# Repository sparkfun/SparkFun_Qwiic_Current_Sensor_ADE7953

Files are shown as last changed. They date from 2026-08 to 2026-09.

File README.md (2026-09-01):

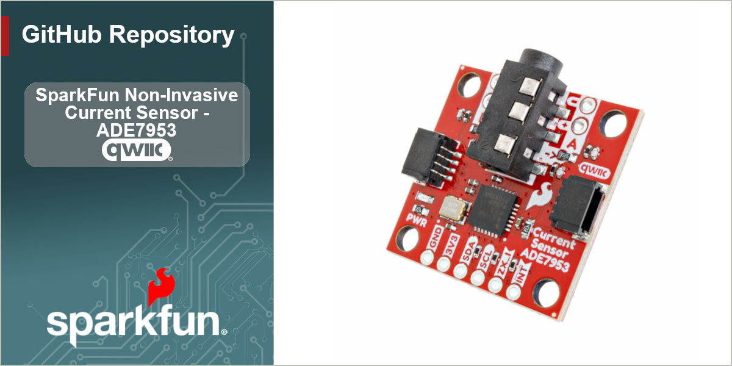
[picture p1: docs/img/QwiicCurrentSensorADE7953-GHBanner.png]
SparkFun Non-Invasive Current Sensor - ADE7953 (Qwiic) (https://www.sparkfun.com/sparkfun-non-invasive-current-sensor-ade7953-qwiic.html)


The [SparkFun Non-Invasive Current Sensor - ADE7953 (Qwiic)](https://www.sparkfun.com/sparkfun-non-invasive-current-sensor-ade7953-qwiic.html) is a dual-channel, non-invasive current measurement breakout built around the ADE7953 energy metering IC from Analog Devices. Using inexpensive SCT-013 split-core current transformers (CT clamps), you can measure AC current on up to two channels without ever breaking a wire. The board accepts CT input through a standard 3.5mm TRRS audio jack or through the A+/A- and B+/B- terminal connections, giving you flexibility for both quick prototyping and permanent installations.

Designed for our [Qwiic ecosystem](https://www.sparkfun.com/qwiic), the ADE7953 handles all of the signal conditioning, sampling, and power calculations on-chip, delivering calibrated current readings over I2C so your host microcontroller can stay focused on application logic. Whether you are building a home energy monitor, an industrial equipment dashboard, or a smart breaker panel, this board gives you metering-grade measurements in a compact, breadboard-friendly package.

## Repository Contents

* **/docs** - Documentation files for GitHub pages
* **/Documents** - Datasheets, additional product information
* **/Hardware** - KiCad design files (.kicad_sch, .kicad_pcb)
* **/Production** - Production panel files

## Documentation

* **[Library](https://github.com/sparkfun/SparkFun_ADE7953_Arduino_Library)** - Arduino library for the SparkFun Non-Invasive Current Sensor - ADE7953 (Qwiic).
* **[Hookup Guide](https://docs.sparkfun.com/SparkFun_Qwiic_Current_Sensor_ADE7953/)** - Basic hookup guide for the SparkFun Non-Invasive Current Sensor - ADE7953 (Qwiic).

## Product Versions

* **[SEN-31409](https://www.sparkfun.com/sparkfun-non-invasive-current-sensor-ade7953-qwiic.html)** - Initial release of the SparkFun Qwiic Current Sensor - ADE7953.

## License Information

This product is _**open source**_!

Please review the LICENSE.md file for license information.

If you have any questions or concerns about licensing, please contact technical support on our [SparkFun forums](https://forum.sparkfun.com/viewforum.php?f=152).

Distributed as-is; no warranty is given.

_- Your friends at SparkFun._

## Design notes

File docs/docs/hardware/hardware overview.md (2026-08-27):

# Hardware Overview

## ADE7953 Single Phase Metering IC

The ADE7953 is a single phase energy measurement IC. It measures both voltage and current along with active and reactive energy. It can also measure instantaneous rms (IRMS) voltage and current. It operates using three high-accuracy sigma-delta ADCs with two current channels. Both channels have a Programmable Gain Amplifier which can also be fine tuned with a digital gain. The ADE7953 communicates over I<sup>2</sup>C, UART and SPI (the SPI pins are *not* broken out on this Qwiic breakout).

The ADE7953 also has dedicated pins for zero-crossing for voltage (not available on this Qwiic breakout) and current to measure line frequency, cycles or to synchronize measurements with the line frequency. It supports EN 50470-1, EN 50470-3, IEC 62053-21, IEC 62053-21, IEC 62053-22 and IEC 62053-23 standards. It accepts a supply voltage up to 3.7V so it works perfectly at the 3.3V of the Qwiic ecosystem. For complete information on the ADE7953, refer to the [datasheet](/ref/ADE7953.pdf).

## Connectors

### Qwiic

The board has a pair of Qwiic connectors for easy integration into a Qwiic circuit. These 4-pin connectors are tied to the board's 3.3V, Ground, SDA and SCL pins to power and communicate over a Qwiic connection by default.

### Current Sensing Connections

The board routes the ADE7953's Channel A current input to a 3.5mm TRRS jack for use with a compatible current transformer/current clamp. The board design is intended to work with a current transformer with a ratio of 2000:1. Channel A and Channel B are also routed to plated through-holes on either side of the TRRS jack for those who prefer a soldered connection or want to use Channel B. Note, the through-hole connections to the ADE7953's current channels operate at a 1:1 ratio and cannot safely measure currents above 100mA without adding in a current transformer with a compatible CT ratio. 

### Plated Through-Hole Header

The 0.1"-spaced plated through-hole (PTH) header on the bottom of the board breaks out the power pins (3.3V and Ground), communication (SDA/TX and SCL/RX) pins, Interrupt and Zero Cross signal pins. 

The Interrupt pin is an active LOW digital output. It can be configured to fire on a variety of events such as overcurrent, zero-crossing or cycle completion without polling. It can be configured to trigger on single events or multiple events at the same time.

The Zero Cross signal (labeled ZX_I) outputs a pulse each time the current waveform crosses zero. This pulse is great for determining line frequency and syncrhonizing measurements to the AC cycle of a connected load.

## LED

This board has a single LED labeled **PWR**. This red LED is a simple status LED to indicate when the board has power.

## Solder Jumpers

The Non-Invasive Current Sensor - ADE7953 has four solder jumpers labeled **SCLK** (some boards may have this jumper mislabeled as SLCK), **CS**, **I<sup>2</sup>C** and **LED**. The list below outlines their functionality, default state and any notes on their use.

* **SCLK** - This three-way jumper works with the CS jumper to set the communication interface used by the ADE7953. The jumper pulls the SCLK pin HIGH/3.3V by default to use the I<sup>2</sup>C interface. Sever the trace between the "top" and center pad and connect the center pad to the "bottom" to pull SCLK LOW/GND to enable UART. Leave the center pad disconnected from the other two pins to enable SPI communication. **NOTE**: This board does *not* route the ADE7953's SCLK and CS pins to dedicated PTHs so SPI is not *technically* supported on this board. Refer to the Troubleshooting section for more information on SPI.
* **CS** - This jumper works with the SCLK jumper to set the ADE7953's communication interface. The jumper pulls the CS pin HIGH to enable I<sup>2</sup>C and UART. Open this jumper to disable both interfaces and to enable SPI. **NOTE**: This board does *not* route the ADE7953's SCLK and CS pins to dedicated PTHs so SPI is not *technically* supported on this board. Refer to the Troubleshooting section for more information on SPI.
* **I<sup>2</sup>C** - This three-way jumper pulls the ADE7953's SDA and SCL lines to 3.3V through a pair of **2.2k&ohm;** resistors. It is CLOSED by default. Completely open this jumper to disable the pull-ups on the data and clock pins.
* **LED** - The LED jumper completes the power LED circuit. It is CLOSED by default. Open this jumper to disable the power LED.

## Board Dimensions

This Qwiic breakout matches the standard Qwiic form-factor and measures 1" x 1" (22.5mm x 22.5mm) and has four mounting holes that fit a 4-40 screw.

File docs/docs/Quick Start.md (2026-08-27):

# Quick Start Guide

In this Quick Start Guide we'll go over how to connect the Non-Invasive Current Sensor - ADE7953 (Qwiic) to an Arduino development board along with a split-core current transformer using the board's 3.5mm TRRS jack to measure current from an AC load. This guide assumes users understand how to use the Arduino IDE and install libraries, assemble Qwiic circuits and measure AC loads with a current transformer. If you're not familiar with these topics, we recommend reading through the more detailed pages in the Hookup Guide.

## Current Sensing Assembly

* Connect the Non-Invasive Current Sensor to the RedBoard using a Qwiic cable.
* Plug the Split-Core Current Transformer into the 3.5mm TRRS jack on the Non-Invasive Current Sensor but leave the clamp **open** and disconnected from an AC load.
* Connect the board to a computer over USB.
* Have the wire for your AC load ready to insert into the Current Transformer's clamp once calibration in the Arduino example finishes.

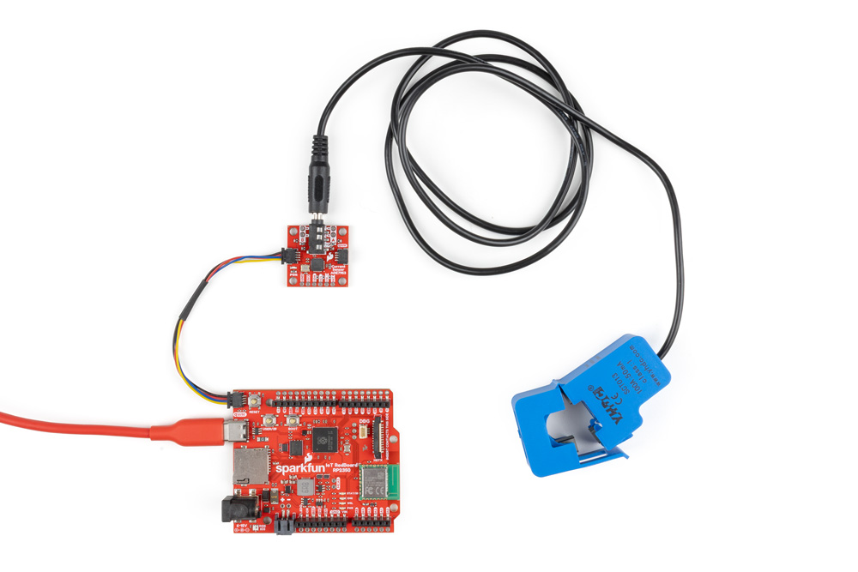
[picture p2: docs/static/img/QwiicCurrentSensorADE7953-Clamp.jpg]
Photo of completed Non-Invasive Current Sensor assembly with RedBoard IoT and Split Core Current Transformer
[]

## Arduino Example

Now we'll use the first example in the SparkFun ADE7953 Arduino library to configure and calibrate the sensor and then print out measured current in Amps. 

* Open the [Arduino IDE](https://www.arduino.cc/en/software/).
* Using the [Arduino Library Manager](https://docs.arduino.cc/software/ide-v2/tutorials/ide-v2-installing-a-library/), install the SparkFun ADE7953 Arduino Library by searching for "SparkFun ADE7953".
    * **Note**: This library was built with the [SparkFun Toolkit Library](https://github.com/sparkfun/SparkFun_Toolkit). Make sure to have the SparkFun Toolkit installed as well.
* Open "Example01_BasicCurrentReading". Select your Board and Port and click the Upload button.
* After the code finishes uploading, open the [serial monitor](https://docs.arduino.cc/software/ide-v2/tutorials/ide-v2-serial-monitor/) with the baud set to **115200**. You should see the code initialize the sensor on the bus and begin auto calibration to zero out the noise floor. Make sure the clamp is **open** during calibration. Once the code finishes calibration and prints out "Calibration done. Reading current...", close the clamp around your AC load and you'll see current measurements in Amps print out every 250ms.

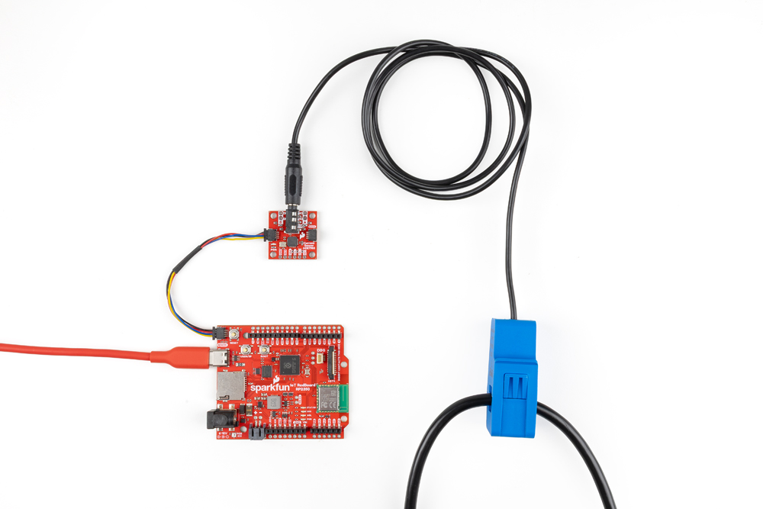
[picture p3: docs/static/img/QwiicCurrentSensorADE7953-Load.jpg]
Completed circuit measuring AC current
[]

As the name suggests, this is the most basic example in the ADE7953 library. The other examples cover how to use other features like zero-crossing, interrupt handling and detailed calibration to offset any noise floor. Read on to the Arduino Examples section for detailed information on most examples included in the library.

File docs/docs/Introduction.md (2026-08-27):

---
slug: /
---

# Introduction

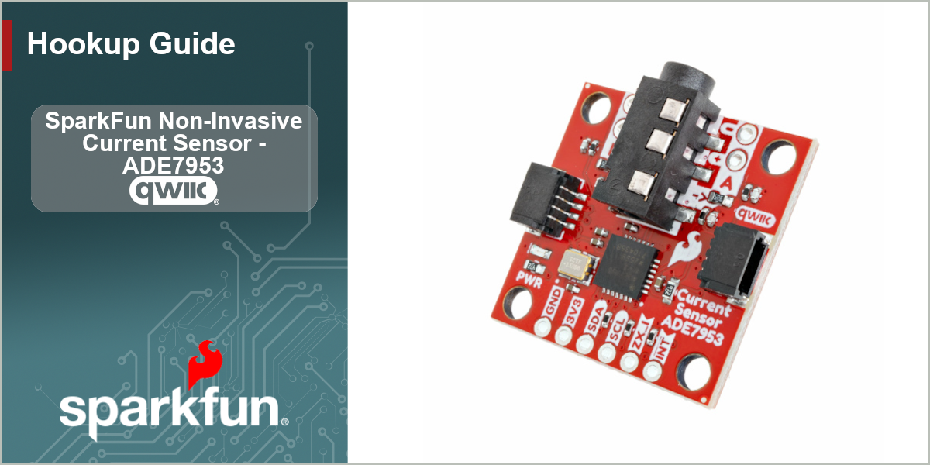
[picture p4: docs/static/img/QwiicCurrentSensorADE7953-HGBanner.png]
Non-Invasive Current Sensor Banner Image
[]

Designed to work with a non-invasive current clamp, the [SparkFun Non-Invasive Current Sensor - ADE7953 (Qwiic)](https://www.sparkfun.com/sparkfun-non-invasive-current-sensor-ade7953-qwiic.html) makes it easy to monitor the power drawn by AC devices over I<sup>2</sup>C without having to disconnect the circuit, cut or splice any wires. The ADE7953 single phase multifunction metering IC from Analog Devices is a single phase metering IC that also can measure neutral current on a second channel.

This board comes with a 3.5mm TRRS jack input that connects to the ADE7953's Current Channel A allowing users to easily connect a [non-invasive current clamp](https://www.sparkfun.com/products/31899) (sometimes referred to as a current clamp) to the board. The board also breaks out both the A and B current channels to plated-through hole pins but does <i>not</i> break out the ADE7953's voltage measurement channel so this board can only measure AC current. **Note**: The A and B PTHs have a 1:1 current transformer ratio and can only measure AC current under 100mA safely. 

In order to follow along with this guide you'll need the SparkFun Non-Invasive Current Sensor - ADE7953 (Qwiic) along with the following items:

* [Split-Core Current Transformer - 100A to 50mA](https://www.sparkfun.com/split-core-current-transformer-100a-to-50ma.html)* (or other current transformer/current clamp)
* [SparkFun RedBoard IoT - RP2350](https://www.sparkfun.com/catalog/product/view/id/17811/s/sparkfun-iot-redboard-rp2350/) (or other Arduino development board)
* [USB-C Cable](https://www.sparkfun.com/usb-a-to-usb-c-cable-1m-usb-2-0-flexible-silicone.html)
* [Qwiic Cable](https://www.sparkfun.com/flexible-qwiic-cable-100mm.html)

*Note:* The [SparkFun Non-Invasive Current Sensor Kit](https://www.sparkfun.com/sparkfun-non-invasive-current-sensor-kit.html) includes the Split-Core Current Transformer.

## Topics Covered

This document contains three main sections: **Quick Start Guide**, **Hardware** and **Software**.

The Quickstart Guide assumes a working knowledge of how to assemble and use Qwiic breakouts, measuring current with a split-core current transformer and using the Arduino IDE. It demonstrates how to connect the Non-Invasive Current Sensor - ADE7953 (Qwiic) to a split-core current transformer and then jumps right into getting the necessary software packages installed to start uploading code in just a few short minutes.

The Hardware pages include a hardware overview that provides a detailed overview of the Non-Invasive Current Sensor - ADE7953 (Qwiic). The Hardware Assembly page goes over the steps required to assemble and use the board to measure current with a compatible Arduino development board.

The Software pages give instructions on how to install the SparkFun ADE7953 Arduino Library and use some of the examples included in it.

## Resources and Documentation

The **Resources** page has the board design files (KiCad files & schematic), relevant documentation (datasheets, white papers, etc.) and other helpful links. Lastly, the **Support** pages include a Troubleshooting page that includes any helpful tips specific to this board as well as information on how to receive technical support from SparkFun.

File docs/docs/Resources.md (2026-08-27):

For more information about the Non-Invasive Current Sensor - ADE7953 (Qwiic), check out the following resources:

* [Schematic](/ref/SparkFun_Qwiic_Current_Sensor_ADE7953.pdf)
* [KiCad Files](/ref/SparkFun_Qwiic_Current_Sensor_ADE7953.zip)
* [Board Dimensions](/ref/SparkFun_Qwiic_Current_Sensor_ADE7953.png)
* [Datasheet](/ref/ADE7953.pdf) (ADE7953)
* [Arduino Library](https://github.com/sparkfun/SparkFun_ADE7953_Arduino_Library)

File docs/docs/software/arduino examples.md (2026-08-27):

# Arduino Examples

Now that we've installed the ADE7953 Library lets take a look at a few of the examples included in it.

## Example 01 - Basic Current Reading

The first example demonstrates the simplest way to read current from the ADE7953. Open the example by navigating to **File** > **Libraries** > **SparkFun ADE7953 Arduino Library** > **Example01_BasicCurrentReading**.

The example sets up the ADE7953 to operate with 16x gain and enables the high-pass filter. After initializing the sensor on the I<sup>2</sup>C bus with these settings, the code performs a calibration of the ADE7953 to zero out the sensor's noise floor. Make sure the clamp is **open** during this process and wait for the code to print "Calibration done. Reading current..." before closing the clamp around the load's wire.

After calibration, the example prints out measured current in Amps every 250ms.

## Examle 02 - Dual Channel Current

The second example shows how to measure RMS current on both Channel A and B. The code configures Channel A as the CT clamp input on the TRRS connector and Channel B as a direct measurement.

## Example 03 - Gain Configuration

Example 3 shows how to configure the PGA (Programmable Gain Amplifier) and the digital (fine) gain on Channel A. The PGA gain controls the amplifier sensitivity. The default is 16x for CT clamp use. The fully available PGA settings are:

``` c++
    ADE7953_PGA_GAIN_1   (1x)
    ADE7953_PGA_GAIN_2   (2x)
    ADE7953_PGA_GAIN_4   (4x)
    ADE7953_PGA_GAIN_8   (8x)
    ADE7953_PGA_GAIN_16  (16x) <-- default
    ADE7953_PGA_GAIN_22  (22x, current channels only)
```

The ADE7953 also provides a digital gain to fine-tune readings on top of the PGA. The example configures it with a simple floating-=point multiplier (1.0 = unity) instead of a raw register value. The code initializes the sensor on the bus and prints out the current PGA gain which is set to 16x by `mySensor.begin()`. After printing this out, the code then adjusts the gain to 8x. You can change this to another of the available PGA settings by adjusting the following line:

```c++ 
 mySensor.setGainIA(ADE7953_PGA_GAIN_8);
```

## Example 04 - Peak Detection

The fourth example shows how to read peak values from Channel A and clear out old peak data every two seconds. The ADE7953 continuously tracks the highest instantaneous current sample since the last reset so you can use this to detect transient events like motor startup surges or inrush current.

The code defines the interval between peak resets in milliseconds. The code defaults to do this every two seconds, adjust the line below to change the interval:

``` c++
const unsigned long kPeakInterval = 2000;
unsigned long lastResetTime = 0;
```

In the setup, the code clears any old peak value by performing an initial read and reset:

``` c++
    mySensor.readAndResetPeakIA();
    lastResetTime = millis();
```

The main loop prints the IRMS value for context, then reads and resets the peak readings and prints out the last peak value read over serial.

## Example 05 - Zero Crossing

Example 5 shows how to configure the zero-crossing (ZX) detection from the ADE7953. This requires connecting the ZX_I pin on the board to a digital input on your microcontroller. The options shown in the code are:

``` c++
    setZXISource()  - //Select Channel A or B as the ZX_I source
    setZXEdge()     - //Choose which edges trigger the ZX output
    enableZXLPF()   - //Enable/disable the zero-crossing low-pass filter
    getPeriod()     - //Read the measured line period from the ZX detector
```

The code defaults to use D2. Adjust this line if using another pin or if no pin is used:

``` c++
// Set to -1 if not wired up — the example will still show register-based readings.
const int kZXIPin = 2;
```

The setup selects Channel A for the ZX_I source, sets the edge detection to trigger on both positive and negative zero crossings and enables the zero-crossing low-pass filter. It includes serial prints to confirm all of the settings:

``` c++
    // Select Channel A as the ZX_I source (false = Channel A, true = Channel B).
    mySensor.setZXISource(false);
    Serial.println("ZX_I source: Channel A");

    // Set edge detection to trigger on both positive and negative zero crossings.
    mySensor.setZXEdge(ADE7953_ZX_EDGE_BOTH);
    Serial.println("ZX edge: Both (positive and negative)");

    // Enable the zero-crossing low-pass filter for cleaner detection.
    mySensor.enableZXLPF(true);
    Serial.println("ZX LPF: Enabled");
```

The main loop then reads the period register. This register represents the line period measured by the zer-crossing detector in the units of the internal clock (223,750 Hz) and prints it out:

``` c++
    uint16_t period = mySensor.getPeriod();

    Serial.print("Period register: ");
    Serial.print(period);
```

It then converts this to an approximate line frequency and measures a full cycle (two zero crossings). Lastly, if the ZX_I pin is connected to a digital input, it prints out the number of crossings counted.

## Example 06 - Interrupt Pin

This example demonstrates how to configure and use the ADE7953's interrupt pin. The Interrupt pin is active LOW and triggers for a variety of events such as overcurrent, zero-crossing or cycle completion without polling. The example defaults to configure an overcurrent threshold on Channel A to trigger the interrupt. 

The code defaults to use D3 on a connected microcontroller. If your microcontroller does not support external interrupts on D3, adjust the line below to a [compatible pin](https://docs.arduino.cc/language-reference/en/functions/external-interrupts/attachInterrupt/):

``` c++
const int kIRQPin = 3;
```

The setup configures the overcurrent threshold in raw ADC counts. Adjust this value depending on your expected current range:

``` c++
    uint32_t overcurrentThreshold = 0x100000;
```

It then enables the overcurrent interrupt on Channel A. This function can be adjusted to enable multiple interrupts using `OR`:

``` c++
    mySensor.setInterruptEnableA(ksfADE7953IrqOI);
```

Finally the setup configures the external IRQ pin to trigger on the falling edge:

``` c++
    pinMode(kIRQPin, INPUT_PULLUP);
    attachInterrupt(digitalPinToInterrupt(kIRQPin), irqISR, FALLING);
```

The main loop then reads and prints the current IRMS value and then prints out whenever an interrupt is triggered as well as the type of interrupt.

## Example 07 - Calibration Offset

Example 7 shows how to use the IMRS offset register to zero out no-load readings on Channel A. This is useful because even with no current flowing, the ADC may report a small IMRS value due to noise. The offset register lets you suptract the baseline noise value for more accurate low-current measurements. Make sure to run this example with NO LOAD on Channel A during the calibration phase.

The setup clears any existing offset before performing calibration and then reads the offset to confirm:

``` c++
    mySensor.setIRmsOffsetA(0);

    // Read the current offset to confirm it is zero.
    int32_t currentOffset = mySensor.getIRmsOffsetA();
    Serial.print("Current IRMS offset: ");
    Serial.println(currentOffset);
```

Next, the code performs the calibration phase and prints out the average of the samples:

``` c++
    Serial.println();
    Serial.println("=== CALIBRATION PHASE ===");
    Serial.println("Ensure no load is connected to Channel A.");
    Serial.print("Averaging ");
    Serial.print(kCalSamples);
    Serial.println(" samples...");
    Serial.println();
```

After letting the readings stabilize, it collects the samples, computes the average baseline and then gives an average no-load reading:

``` c++
    uint32_t sum = 0;
    for (int i = 0; i < kCalSamples; i++)
    {
        uint32_t sample = mySensor.getIRmsA();
        Serial.print("  Sample ");
        Serial.print(i + 1);
        Serial.print(": ");
        Serial.println(sample);
        sum += sample;
        delay(100);
    }

    uint32_t average = sum / kCalSamples;
    Serial.println();
    Serial.print("Average no-load reading: ");
    Serial.println(average);
```

The final stage of calibration writes the negative of the average readings as the offset for the ADE7953 to subtract from the squared signal before taking the root to essentially remove the noise floor:

``` c++
    currentOffset = mySensor.getIRmsOffsetA();
    Serial.print("IRMS offset is now: ");
    Serial.println(currentOffset);
```

Once the calibration process completes, the code prints out "CALIBRATION COMPLETE". Now connect a load and the code will print out IMRS on Channel A with the calibrated value every 500ms.

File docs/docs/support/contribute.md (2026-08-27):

# Contribute

## Improve our Documentation

All of this documentation can be modified by you! Please help us make it better.

* These pages are contained in the [`docs` folder of the SparkFun Qwiic Qwiic Current Sensor INA2XX repository](https://github.com/sparkfun/SparkFun_Qwiic_Current_Sensor_INA2XX/tree/main/docs).

### Submit a Correction

1. Fork this repo
2. Add your corrections or improvements to the markdown file
3. File a pull request with your changes, and enjoy making the ~~words~~ ~~worlds~~ world a better place.
    * Once received, the documentation specialist will automatically be notified.
    * We will review your suggested improvements to make sure they are correct and fit within our documentation standards.

## Improve our Hardware Design

This hardware design is open-source! Please help us make it better.

* Our board design files are contained in the [`Hardware` folder of the SparkFun Qwiic Qwiic Current Sensor INA2XX repository](https://github.com/sparkfun/SparkFun_Qwiic_Current_Sensor_INA2XX/tree/main/Hardware).

### Submit a Design Improvement

1. Fork this repo
2. Add your design improvements
3. File a pull request with your changes, and enjoy making the ~~words~~ ~~worlds~~ world a better place.
    * Once received, the engineer in charge of the original design will automatically be notified.
    * We will review your suggested improvements, if they are within our board design standards and meet our product design requirements, we will flag these changes for our next board revision. *(Please note, that even if your suggestion is accepted, these changes may not be immediate. We may have to cycle through our current product inventory first.)*

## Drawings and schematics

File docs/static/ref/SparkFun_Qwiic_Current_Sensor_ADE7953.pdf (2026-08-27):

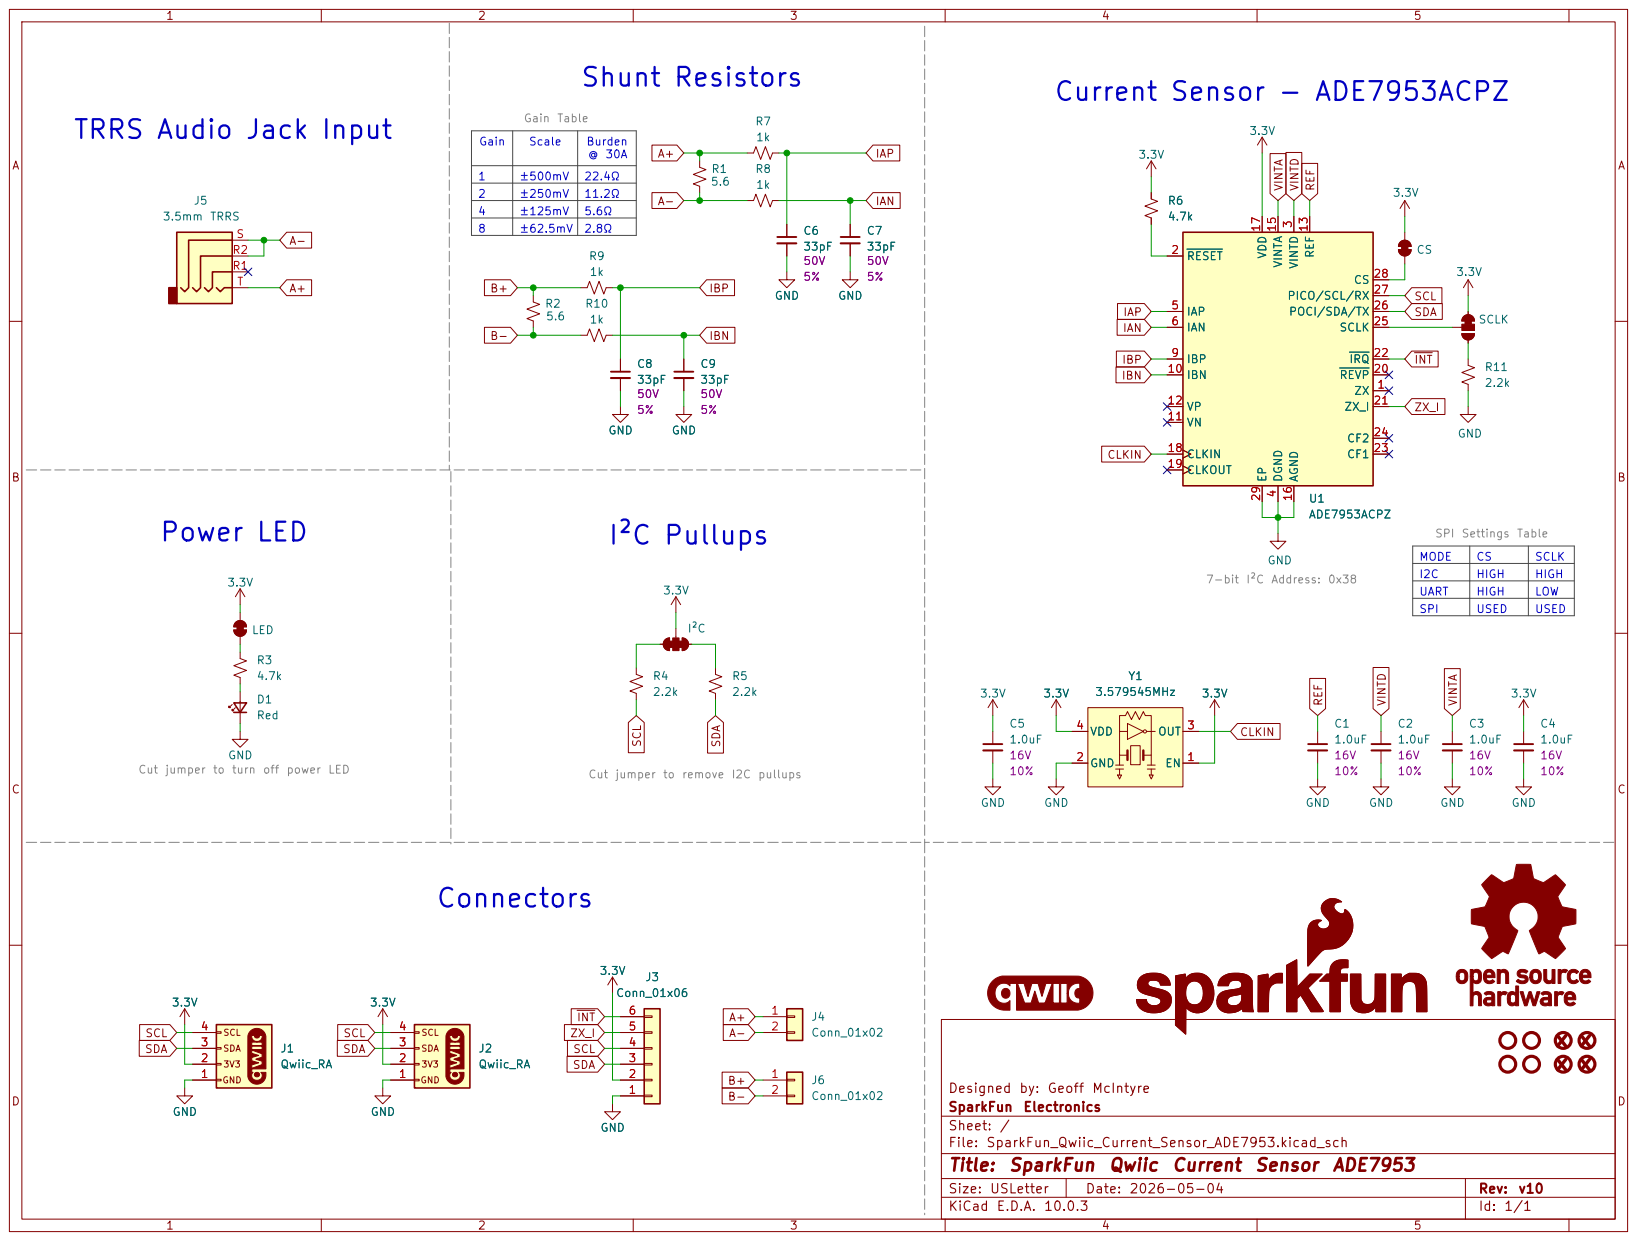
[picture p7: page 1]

Gain Table TRRS Audio Jack Input

Gain | ±500mV Scale | 22.4Ω Burden @ 30A 1

2 | ±250mV | 11.2Ω
4 | ±125mV | 5.6Ω
8 | ±62.5mV | 2.8Ω

SCLK 25 POCI/SDA/TX 26 PICO/SCL/RX 27 CS 28 EP 29 R6

I²C Pullups
SPI Settings Table Cut jumper to remove I2C pullups

7-bit I²C Address: 0x38 Power LED

MODE | CS | SCLK
I2C | HIGH | HIGH
UART | HIGH | LOW
SPI | USED | USED

Designed by: Geoff McIntyre
SparkFun Electronics
Sheet: /
File: SparkFun_Qwiic_Current_Sensor_ADE7953.kicad_sch
Title: SparkFun Qwiic Current Sensor ADE7953

Size: USLetter | Rev: v10
KiCad E.D.A. 10.0.3 | Id: 1/1

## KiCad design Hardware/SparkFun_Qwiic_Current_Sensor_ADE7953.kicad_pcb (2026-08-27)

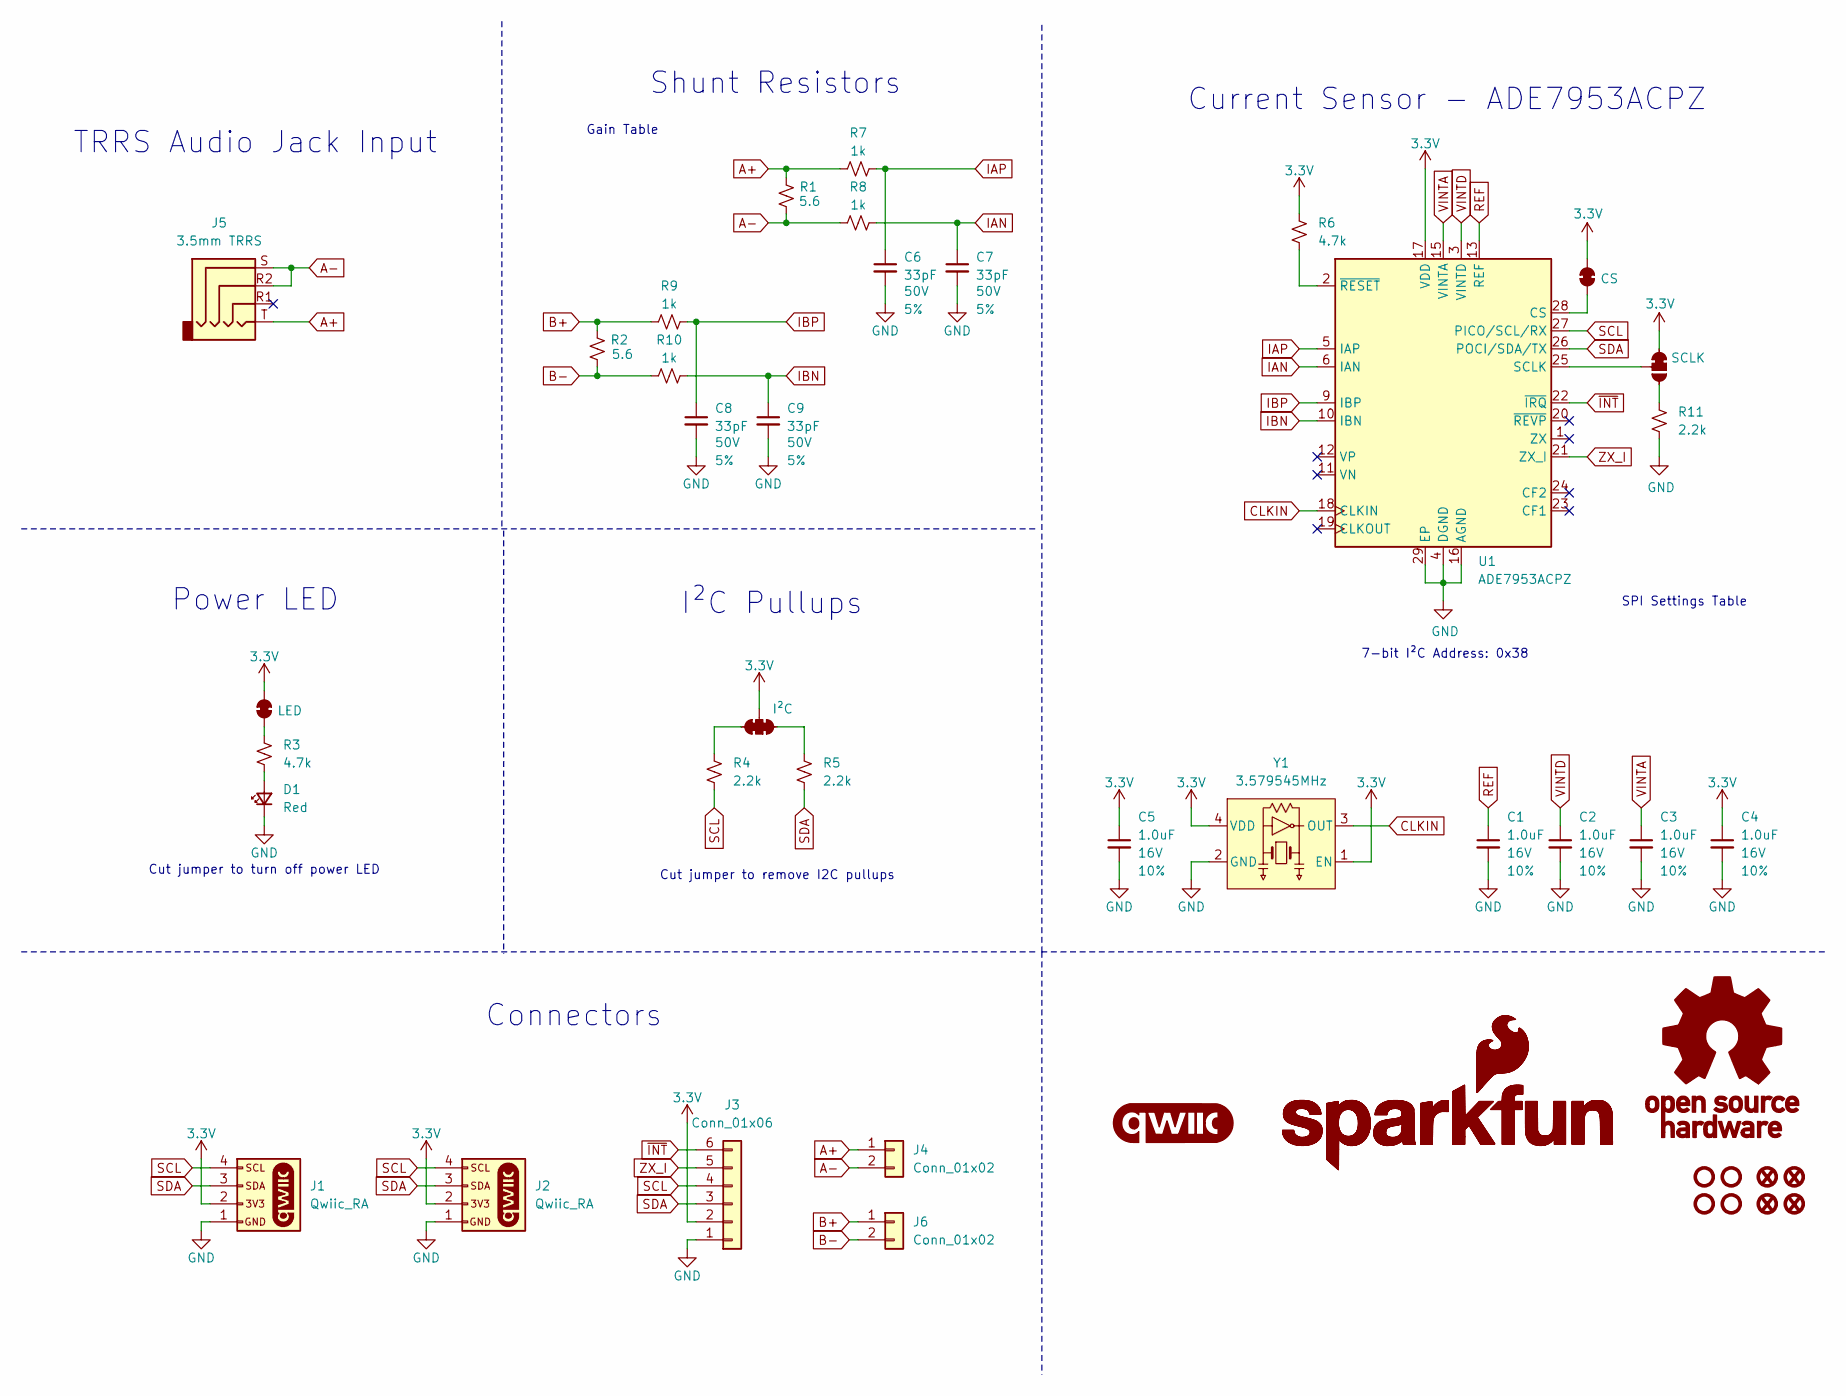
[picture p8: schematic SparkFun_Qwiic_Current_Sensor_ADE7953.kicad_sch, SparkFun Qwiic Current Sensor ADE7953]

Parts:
C1, C2, C3, C4, C5: 1.0uF; C_0402_1005Metric; Voltage 16V; Tolerance 10%
C6, C7, C8, C9: 33pF; C_0402_1005Metric; Voltage 50V; Tolerance 5%
D1: Red; LED_0603_1608Metric_Red
FID1, FID2, FID3, FID4: Fiducial_0.5mm; Fiducial_0.5mm_Mask1mm
G1: qwiic_Logo
G2: SparkFun_Logo; SparkFun_Logo_8mm
G3: SparkFun_Logo
G4: OSHW_Logo; Creative_Commons_License
J1, J2: Qwiic_RA; JST_1x04_P1.0mm_Horizontal_SMD
J3: Conn_01x06; 1x06_P2.54mm
J4, J6: Conn_01x02; 1x02_P2.54mm
J5: 3.5mm TRRS; Audio_Jack_3.5mm_TRRS_SMD_RA
JP1: LED; Jumper_2_NC_Trace
JP2: I²C; Jumper_3_NC-2_Trace
JP3: SCLK; Jumper_3_NC-1_Trace
JP4: CS; Jumper_2_NC_Trace
R1, R2: 5.6; R_0603_1608Metric
R3, R6: 4.7k; R_0603_1608Metric
R4, R5, R11: 2.2k; R_0402_1005Metric
R7, R8, R9, R10: 1k; R_0402_1005Metric
ST1, ST2, ST3, ST4: Standoff
U1: ADE7953ACPZ; QFN-28-1EP_4x4_5mmx5mm; Manufacturer_Part_Number ADE7953ACPZ; Mouser Part Number 584-ADE7953ACPZ
Y1: 3.579545MHz; Crystal_SMD_3.2x2.5mm

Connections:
3.3V: C4.1, C5.1, J1.2, J2.2, J3.2, JP1.2 (B), JP2.2 (B), JP3.1 (A), JP4.2 (B), R6.2, U1.7 (PULL_HIGH_1), U1.8 (PULL_HIGH_2), U1.17 (VDD), Y1.1 (EN), Y1.4 (VDD)
A+: J4.1, J5.T, R1.2, R7.1
A-: J4.2, J5.R2, J5.S, R1.1, R8.1
B+: J6.1, R2.2, R9.1
B-: J6.2, R2.1, R10.1
CLKIN: U1.18 (CLKIN), Y1.3 (OUT)
GND: C1.2, C2.2, C3.2, C4.2, C5.2, C6.2, C7.2, C8.2, C9.2, D1.1 (K), J1.1, J2.1, J3.1, R11.1, U1.4 (DGND), U1.14 (PULL_LOW), U1.16 (AGND), U1.29 (EP), Y1.2 (GND)
IAN: C7.1, R8.2, U1.6 (IAN)
IAP: C6.1, R7.2, U1.5 (IAP)
IBN: C9.1, R10.2, U1.10 (IBN)
IBP: C8.1, R9.2, U1.9 (IBP)
unnamed: D1.2 (A), R3.1
unnamed: JP1.1 (A), R3.2
unnamed: JP2.1 (A), R5.2
unnamed: JP2.3 (C), R4.2
unnamed: JP3.2 (B), U1.25 (SCLK)
unnamed: JP3.3 (C), R11.2
unnamed: JP4.1 (A), U1.28 (CS)
unnamed: R6.1, U1.2 (~RESET)
REF: C1.1, U1.13 (REF)
SCL: J1.4, J2.4, J3.4, R4.1, U1.27 (PICO/SCL/RX)
SDA: J1.3, J2.3, J3.3, R5.1, U1.26 (POCI/SDA/TX)
VINTA: C3.1, U1.15 (VINTA)
VINTD: C2.1, U1.3 (VINTD)
ZX_I: J3.5, U1.21 (ZX_I)
~INT: J3.6, U1.22 (~IRQ)

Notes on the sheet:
SPI Settings Table
Current Sensor - ADE7953ACPZ
Shunt Resistors
TRRS Audio Jack Input
7-bit I²C Address: 0x38
Cut jumper to turn off power LED
Power LED
Cut jumper to remove I2C pullups
Gain Table
Connectors
I²C Pullups

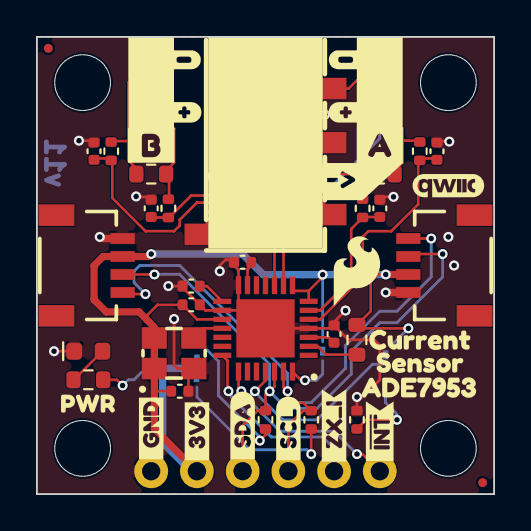
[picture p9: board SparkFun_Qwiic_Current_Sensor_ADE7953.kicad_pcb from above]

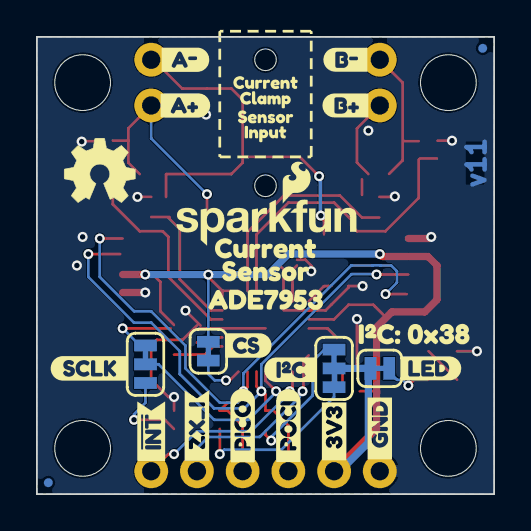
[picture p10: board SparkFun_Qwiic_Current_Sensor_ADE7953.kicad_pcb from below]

Board: 2 copper layers, 25.4 x 25.4 mm, 83 parts (29 on the bottom side), 26 nets.

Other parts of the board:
Ref**: Val**; OSHW_Logo_4mm
kibuzzard-6A8F671A: G***; kibuzzard-6A8F671A
kibuzzard-6A8F6918: G***; kibuzzard-6A8F6918
kibuzzard-6A8F6922: G***; kibuzzard-6A8F6922
kibuzzard-6A3051E6: G***; kibuzzard-6A3051E6
kibuzzard-69F8C340: G***; kibuzzard-69F8C340
kibuzzard-69F8FC1F, kibuzzard-69F8FC1F#2: G***; kibuzzard-69F8FC1F
kibuzzard-69F8FC56, kibuzzard-69F8FC56#2: G***; kibuzzard-69F8FC56
kibuzzard-69F8FCF4: G***; kibuzzard-69F8FCF4
kibuzzard-69F8FD80: G***; kibuzzard-69F8FD80
kibuzzard-69FA12A1, kibuzzard-69FA12A1#2: G***; kibuzzard-69FA12A1
kibuzzard-69FA12DB: G***; kibuzzard-69FA12DB
kibuzzard-69FA13A0: G***; kibuzzard-69FA13A0
kibuzzard-69FA13AB: G***; kibuzzard-69FA13AB
kibuzzard-69FA13C4: G***; kibuzzard-69FA13C4
kibuzzard-69FA13D5: G***; kibuzzard-69FA13D5
kibuzzard-69FA128B, kibuzzard-69FA128B#2: G***; kibuzzard-69FA128B
kibuzzard-69FA1293, kibuzzard-69FA1293#2: G***; kibuzzard-69FA1293
kibuzzard-69FCD097: G***; kibuzzard-69FCD097
kibuzzard-69FCDE2E: G***; kibuzzard-69FCDE2E
kibuzzard-69FD0DBC: G***; kibuzzard-69FD0DBC
kibuzzard-69FD0DD3: G***; kibuzzard-69FD0DD3
kibuzzard-69FD0DDA: G***; kibuzzard-69FD0DDA
kibuzzard-69FD0F08: G***; kibuzzard-69FD0F08
kibuzzard-69FD10A0: G***; kibuzzard-69FD10A0
kibuzzard-69FD10AE: G***; kibuzzard-69FD10AE
kibuzzard-69FD1032: G***; kibuzzard-69FD1032
kibuzzard-69FD1060: G***; kibuzzard-69FD1060
kibuzzard-689A66E2: G***; kibuzzard-689A66E2
kibuzzard-689A66E9: G***; kibuzzard-689A66E9
kibuzzard-689A66EE: G***; kibuzzard-689A66EE
kibuzzard-689A66F4: G***; kibuzzard-689A66F4
kibuzzard-689A642E: G***; kibuzzard-689A642E
kibuzzard-689A6721: G***; kibuzzard-689A6721
kibuzzard-689A6728: G***; kibuzzard-689A6728
kibuzzard-689A6796: G***; kibuzzard-689A6796

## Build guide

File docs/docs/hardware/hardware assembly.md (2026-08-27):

# Hardware Assembly

## Qwiic Assembly

Start by connecting the Non-Invasive Current Sensor - ADE7953 (Qwiic) to a Qwiic compatible dev board (a RedBoard IoT - RP2350 is used in the photo below). After connecting it to the RedBoard, plug the RedBoard into a computer over USB-C.

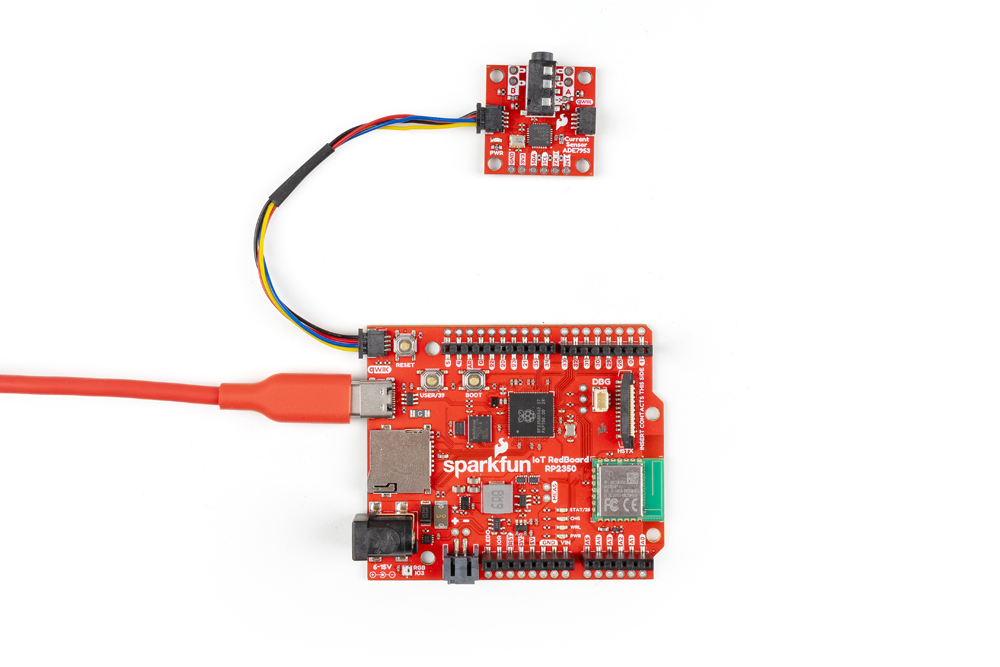
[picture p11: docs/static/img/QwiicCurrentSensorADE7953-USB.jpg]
Non-Invasive Current Sensor ADE7953 connected to RedBoard IoT
[]

## Current Transformer/Current Clamp Assembly

Now plug the current transformer into the Non-Invasive Current Sensor's 3.5mm TRRS jack. We recommend leaving the clamp open and disconnected from an AC load prior to performing calibration using the SparkFun ADE7953 Arduino Library to reduce the noise from the clamp.

[Current Transformer connected to 3.5mm TRRS Jack]

## Channel A and Channel B Direct Connection

The Non-Invasive Current Sensor board is designed to work with a current transformer with a CT ratio of 2000:1 connected to the 3.5mm TRRS jack. The through-hole connections to Channel A and B do not have any extra current transformation ratio integrated and operate at a 1:1 ratio. As a result, AC loads connected to these pins should not exceed **100mA**. Connecting to Channel B requires soldering to the through-hole pins.

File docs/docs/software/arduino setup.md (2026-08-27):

# Arduino Library Setup

This section assumes you are using the latest version of the Arduino IDE on your desktop. If this is your first time using Arduino IDE, library, or board add-ons, we recommend reading through the following tutorials.

- [Installing the Arduino IDE](https://learn.sparkfun.com/tutorials/installing-arduino-ide)
- [Installing an Arduino Library](https://learn.sparkfun.com/tutorials/installing-an-arduino-library)
- [Installing Board Definitions in the Arduino IDE](https://learn.sparkfun.com/tutorials/installing-board-definitions-in-the-arduino-ide)

## SparkFun ADE7953 Arduino Library Installation

This library is built using the [SparkFun Toolkit](https://github.com/sparkfun/SparkFun_Toolkit) so you'll need to make sure that is installed before using this library. Install the SparkFun Toolkit with the Arduino Library manager by searching "SparkFun Toolkit" and installing the latest version. Users who prefer manually installing Arduino Libraries can download it from the [GitHub Repository](https://github.com/sparkfun/SparkFun_Toolkit).

The SparkFun ADE7953 Arduino Library lets you quickly set up, configure and receive data from the ADE7953 and includes eight examples. Install the library using the Arduino Library Manager tool by searching for "SparkFun ADE7953" and install the latest version. If you'd prefer to manually install the library, you can download it from the [GitHub Repository](https://github.com/sparkfun/SparkFun_ADE7953_Arduino_Library) or you can download a ZIP of the repository [here](https://github.com/sparkfun/SparkFun_ADE7953_Arduino_Library/archive/refs/heads/main.zip).

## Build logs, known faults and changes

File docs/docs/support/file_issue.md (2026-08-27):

# Submit Issues

## Support

If you need technical assistance and more information on a product that is not working as you expected, visit the [SparkFun Community](https://community.sparkfun.com). The community forums are monitored by the SparkFun Technical Support Team and the SparkFun community as a whole.

## Existing Issue

Spot something wrong? Please check the list of reported and fixed issues  .  in this repository.

## Discrepancies in the Documentation

All of this documentation can be modified by you! Please help us make it better.

* The documentation files for these pages are contained in the [`docs` folder of the SparkFun Qwiic Qwiic Current Sensor INA2XX repository](https://github.com/sparkfun/SparkFun_Qwiic_Current_Sensor_INA2XX/tree/main/docs).

### Spot something wrong?

If a section of the documentation is incorrect, please [open an issue](https://github.com/sparkfun/SparkFun_Qwiic_Current_Sensor_INA2XX/issues) and let us know.

### Do you have a suggested correction?

1. With a GitHub account, fork this repo
2. Add your correction(s) or improvement(s) to the markdown file(s)
3. File a pull request with your changes, and enjoy making the ~~words~~ ~~worlds~~ world a better place.
    * Once received, the documentation specialist will automatically be notified.
    * We will review your suggested improvement(s) to make sure they are correct and fit within our documentation standards.

## Problems in the Hardware Design

All of our designs are open-source! Please help us make it better.

* Our board design files are contained in the [`Hardware` folder of the SparkFun Qwiic Qwiic Current Sensor INA2XX repository](https://github.com/sparkfun/SparkFun_Qwiic_Current_Sensor_INA2XX/tree/main/Hardware).

### Does something not make sense?

If part of the design is confusing, please [open an issue](https://github.com/sparkfun/SparkFun_Qwiic_Current_Sensor_INA2XX/issues) and let us know.

### Did we forget to include an important function of the board?

Please keep in mind that we may intentionally exclude certain functions of the board to meet our product design requirements.

If part of the board's functionality is missing, please [open an issue](https://github.com/sparkfun/SparkFun_Qwiic_Current_Sensor_INA2XX/issues) and file a feature request.

### Do you wish to contribute directly to improving the board design?

1. With a GitHub account, Fork this repo
2. Add your design improvement(s)
3. File a pull request with your changes, and enjoy making the ~~words~~ ~~worlds~~ world a better place.
    * Once received, the engineer in charge of the original design will automatically be notified.
    * We will review your suggested improvement(s), if they are within our board design standards and meet our product design requirements, we will flag these changes for our next board revision. *(Please note, that even if your suggestion is accepted, these changes may not be immediate. We may have to cycle through our current product inventory first.)*

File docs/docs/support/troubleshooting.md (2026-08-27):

# Troubleshooting

## Channel A and Channel B Direct Connection

The Non-Invasive Current Sensor board is designed to work with a current transformer with a CT ratio of 2000:1 connected to the 3.5mm TRRS jack. The through-hole connections to Channel A and B do not have any extra current transformation ratio integrated and operate at a 1:1 ratio. As a result, AC loads connected to these pins should not exceed **100mA**.

## ADE7953 SPI Interface

The Non-Invasive Current Sensor board design only supports the ADE7953's I<sup>2</sup>C and UART interfaces as it does not break out the SCLK and CS pins for communicating over SPI. While not supported by SparkFun, if you need to use the ADE7953 over SPI you can adjust the SCLK and CS jumpers to enable SPI and then carefully solder to the SCLK and CS solder jumper pads to make those connections. 

## Support

If you need technical assistance or more information on a product that is not working as you expected, we recommend heading on over to the [SparkFun Technical Assistance](https://www.sparkfun.com/technical_assistance) page for some initial troubleshooting.

If you need technical assistance and more information on a product that is not working as you expected, visit the [SparkFun Community](https://community.sparkfun.com). The community forums are monitored by the SparkFun Technical Support Team and the SparkFun community as a whole. If this is your first visit to our forum, you'll need to create a [Forum Account](https://forum.sparkfun.com/ucp.php?mode=register) to post questions.

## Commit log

2026-05-04 Re-arranged File Structure to match standard
    [SparkFun_Qwiic_Current_Sensor_ADE7953.kicad_pcb, SparkFun_Qwiic_Current_Sensor_ADE7953.kicad_sch]
2026-05-04 Updated PCB and Schematic
    [SparkFun_Qwiic_Current_Sensor_ADE7953.kicad_pcb, SparkFun_Qwiic_Current_Sensor_ADE7953.kicad_sch]
2026-05-04 Updated IC Schematic Symbols
    [SparkFun_Qwiic_Current_Sensor_ADE7953.kicad_sch]
2026-05-04 Updated PCB Layout
    [SparkFun_Qwiic_Current_Sensor_ADE7953.kicad_pcb, SparkFun_Qwiic_Current_Sensor_ADE7953.kicad_sch]
2026-05-05 Added silkscreen and minor alignment fixes
    [SparkFun_Qwiic_Current_Sensor_ADE7953.kicad_pcb]
2026-05-05 Added XTAL Osc.
    [SparkFun_Qwiic_Current_Sensor_ADE7953.kicad_pcb, SparkFun_Qwiic_Current_Sensor_ADE7953.kicad_sch]
2026-05-05 Fixed Reset Pin and Shunt Resistors
    [SparkFun_Qwiic_Current_Sensor_ADE7953.kicad_pcb, SparkFun_Qwiic_Current_Sensor_ADE7953.kicad_sch]
2026-05-08 Implemented changes after design review
    [SparkFun_Qwiic_Current_Sensor_ADE7953.kicad_pcb, SparkFun_Qwiic_Current_Sensor_ADE7953.kicad_sch]
2026-05-08 Moved R11
    [SparkFun_Qwiic_Current_Sensor_ADE7953.kicad_pcb]
2026-05-08 Updated part libraries
    [SparkFun_Qwiic_Current_Sensor_ADE7953.kicad_pcb, SparkFun_Qwiic_Current_Sensor_ADE7953.kicad_sch]
2026-05-08 Add Gerbers
    [SparkFun_Qwiic_Current_Sensor_ADE7953.GBL, SparkFun_Qwiic_Current_Sensor_ADE7953.GBO, SparkFun_Qwiic_Current_Sensor_ADE7953.GBP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]
2026-05-08 Replaced 4x4mm with 5x5mm footprint
    [SparkFun_Qwiic_Current_Sensor_ADE7953.kicad_pcb]
2026-05-08 Updated a few vias
    [SparkFun_Qwiic_Current_Sensor_ADE7953.kicad_pcb]
2026-05-11 Changed 4x4 chip size to 5x5mm
    [SparkFun_Qwiic_Current_Sensor_ADE7953.GBL, SparkFun_Qwiic_Current_Sensor_ADE7953.GBO, SparkFun_Qwiic_Current_Sensor_ADE7953.GBP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]
2026-06-15 Updated number for Reds, added I2C Addr
    [SparkFun_Qwiic_Current_Sensor_ADE7953.kicad_pcb]
2026-06-18 Updated PCB based on Design Review II feedback
    - Updated schematic I2C labels
    - Updated component silkscreens and courtyards
    [SparkFun_Qwiic_Current_Sensor_ADE7953.kicad_pcb, SparkFun_Qwiic_Current_Sensor_ADE7953.kicad_sch]
2026-06-22 Fixed 8mil traces -> 6mil traces
    [SparkFun_Qwiic_Current_Sensor_ADE7953.kicad_pcb]
2026-08-27 Updated PCB to v1.1
    [SparkFun_Qwiic_Current_Sensor_ADE7953.kicad_pcb, SparkFun_Qwiic_Current_Sensor_ADE7953.kicad_sch]

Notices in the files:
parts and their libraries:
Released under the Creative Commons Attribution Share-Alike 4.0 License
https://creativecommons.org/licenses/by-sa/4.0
